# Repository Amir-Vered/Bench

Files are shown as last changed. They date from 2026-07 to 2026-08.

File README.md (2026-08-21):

# Bench

<p align="center">
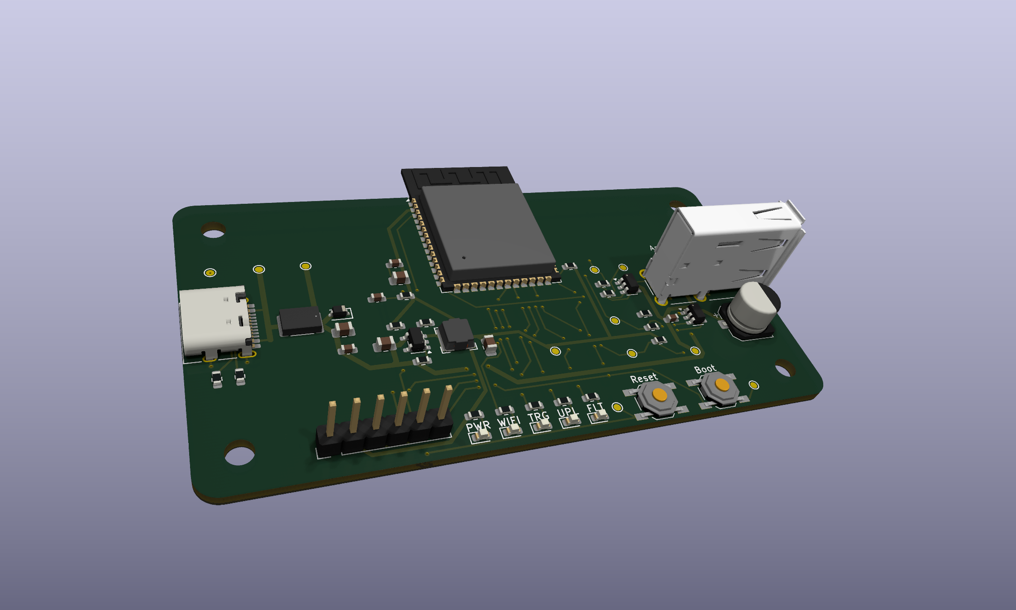
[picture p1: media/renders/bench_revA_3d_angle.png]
Bench Rev A render
  
</p>

<p align="center">
  
  
  
  
</p>

<p align="center">
  🎥 <a href="https://youtu.be/uZiKh8IRC8s">Video</a> &nbsp;•&nbsp; 🌐 <a href="https://amirvered.com/project/bench">Writeup</a>
</p>

<p align="center">
  <a href="#project-goals">Project Goals</a> •
  <a href="#system-overview">System Overview</a> •
  <a href="#diagrams">Diagrams</a> •
  <a href="#hardware">Hardware</a> •
  <a href="#software">Software</a> •
  <a href="#license">License</a>
</p>

---

*Bench... and it's not made out of wood?*

Here's the pitch:

TL;DR wires are annoying, let's put Bench in the middle of the Arduino workflow.

I love Arduino, it's perfect for prototyping your projects before making your PCBs. 
But, idk about you, the most annoying thing to me is the fact that the board is tied to my laptop.
And it's not a graceful connection, no, these wires are some of the most stale twisted things you've ever used, especially the uni lab ones.
This gets even worse when you're using a desktop computer.
But what if we put a device in the middle?

Enter: Bench.

Bench is a wifi upload dock for Arduino (built primarily for the Uno R3 because it's the one I use most).
Compile your sketch, run a command, and boom, it uploads to your device somewhere else.
No more wire, Arduino dev becomes a little less life-draining.

This is a simple little project, but it's open source, and I hope you find some use out of it.
Feel free to leave issues, fork, or really do whatever you want with it.

## Project Goals

My goals for this project were to:
- Improve the Arduino dev experience
- Develop my hardware, firmware, and software design skills
- Document a project from beginning to end

## System Overview

Let's get into the details.

At a high level:

1. The laptop compiles an Arduino sketch into a `.hex` file.
2. The CLI sends the `.hex` file to Bench over Wi-Fi.
3. The ESP32-S3 on Bench receives the upload request.
4. Bench opens a USB host serial connection to the Arduino Uno R3.
5. Bench triggers the Uno bootloader window.
6. Bench uploads the program to the ATmega328P flash memory.

Bench does not compile Arduino code on-board; compilation happens on the laptop.

## Diagrams

### Labeled Board

<p align="center">
  Bench Rev A labeled board
</p>

### System Block Diagram

<p align="center">
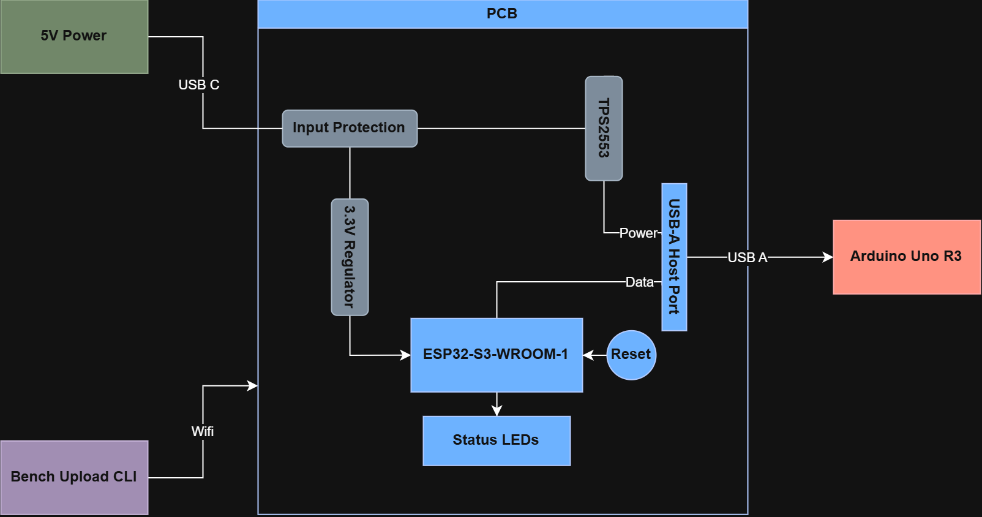
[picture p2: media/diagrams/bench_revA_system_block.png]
Bench Rev A system block diagram
  
</p>

### Power Path

<p align="center">
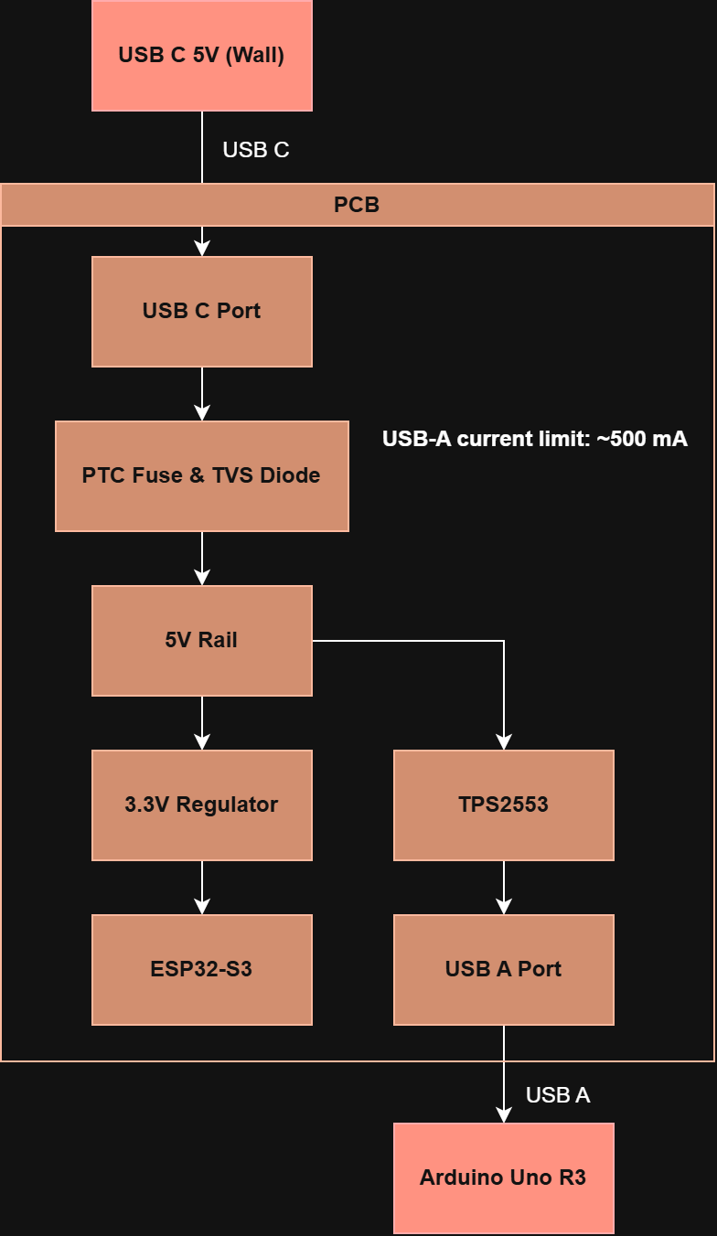
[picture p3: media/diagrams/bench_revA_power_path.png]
Bench Rev A power path
  
</p>

### Upload/Data Flow

<p align="center">
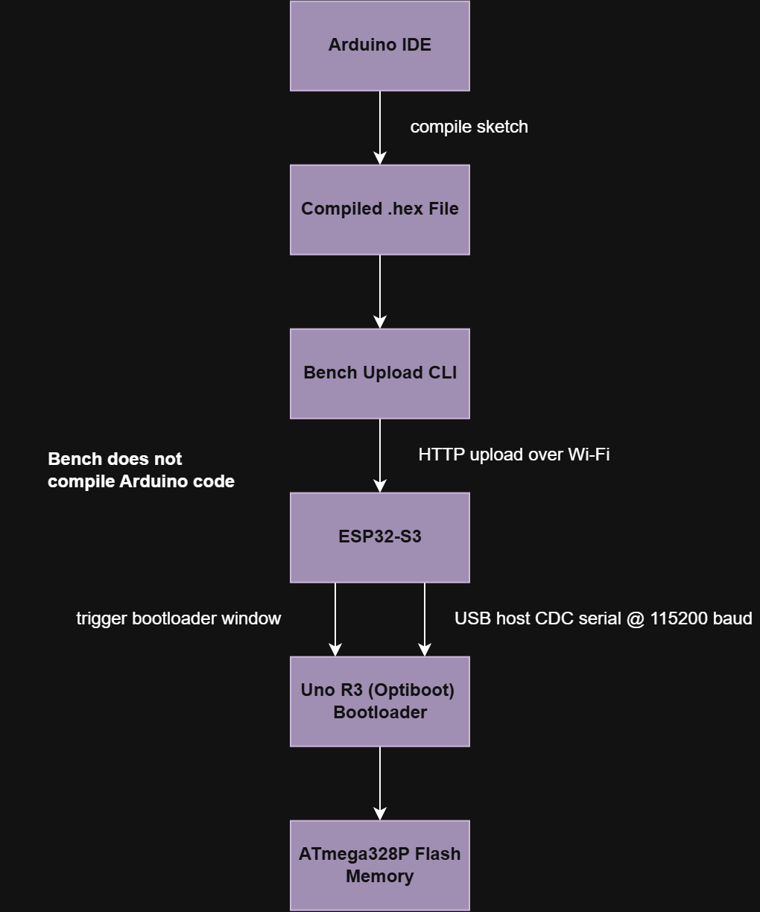
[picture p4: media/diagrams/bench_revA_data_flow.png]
Bench Rev A data flow
  
</p>

## Repository Structure

```text
bench/
├── hardware/
│   ├── kicad/
│   └── exports/
├── software/
│   ├── mock/
│   │   └── bench-mock-server/
│   ├── cli/
│   │   └── bench-upload/
│   └── firmware/
│       └── bench-fw/
├── media/
│   ├── diagrams/
│   ├── renders/
│   └── screenshots/
├── LICENSE-SOFTWARE
├── LICENSE-HARDWARE
└── README.md
```

## Hardware

Bench is built around the ESP32-S3-WROOM-1.

Major hardware blocks include:

- USB-C 5V input
- Input protection using a PTC fuse and TVS diode
- 3.3V buck regulator for the ESP32-S3
- ESP32-S3-WROOM-1 Wi-Fi microcontroller
- USB-A host output for the Arduino Uno R3
- TPS2553 current-limited USB power switch
- USB data ESD protection
- Status LEDs for power, Wi-Fi, target, upload, and fault states
- Reset and boot/config buttons

## Software

Bench includes three software components:

```text
software/
├── mock/
│   └── bench-mock-server/
├── cli/
│   └── bench-upload/
└── firmware/
    └── bench-fw/
```

### Mock Server

The mock server simulates a Bench device on a local computer. It is used to test the CLI without Bench hardware.

```powershell
cd software\mock\bench-mock-server
python -m venv .venv
.venv\Scripts\Activate.ps1
python -m pip install --upgrade pip
python -m pip install -e .
bench-mock --port 8080
```

Test the mock server:

```text
http://127.0.0.1:8080/api/v1/status
```

### CLI

The Bench Upload CLI runs on the laptop, and can communicate with the firmware or mock server.

```powershell
cd software\cli\bench-upload
python -m venv .venv
.venv\Scripts\Activate.ps1
python -m pip install --upgrade pip
python -m pip install -e .
```

#### *Here's how to use the commands, demoed on the mock server...*

Check Bench status:

```powershell
bench status --device http://localhost:8080
```

Upload a precompiled Intel HEX file:

```powershell
bench upload --hex path\to\sketch.ino.hex --device http://localhost:8080
```

Upload without target reset:

```powershell
bench upload --hex path\to\sketch.ino.hex --no-reset --device http://localhost:8080
```

Upload without verify:

```powershell
bench upload --hex path\to\sketch.ino.hex --no-verify --device http://localhost:8080
```

Compile an Arduino sketch with Arduino CLI, then upload:

```powershell
bench upload path\to\Blink --fqbn arduino:avr:uno --device http://localhost:8080
```

### Firmware

The firmware is an ESP-IDF project for the ESP32-S3.

```powershell
cd software\firmware\bench-fw
idf.py set-target esp32s3
idf.py build
```

Wi-Fi settings are configured locally with:

```powershell
idf.py menuconfig
```

Then open:

```text
Bench Configuration
```

and set:

```text
Wi-Fi SSID
Wi-Fi password
```

## Firmware Features

Current firmware includes:

- Wi-Fi station startup
- HTTP API server
    - `GET /api/v1/status`
    - `POST /api/v1/target/power`
    - `POST /api/v1/target/reset`
    - `GET /api/v1/logs`
    - `POST /api/v1/upload`
    - `GET /api/v1/upload/{job_id}`
- ESP32-S3 USB host CDC
- Arduino Uno R3 Optiboot/STK500 upload path (🤞😩)
- GPIO control for TPS2553 target power
- GPIO control for status LEDs

The firmware builds successfully for ESP32-S3, but I haven't had the chance to test it on hardware, so be careful.

## API Overview

Bench firmware and the mock server expose the same main HTTP API shape.

```text
GET  /api/v1/status
POST /api/v1/upload
GET  /api/v1/upload/{job_id}
POST /api/v1/target/power
POST /api/v1/target/reset
GET  /api/v1/logs
```

Primary upload states:

```text
idle
receiving
opening_target
bootloader_sync
uploading
verifying
success
failed
fault
```

Primary error codes:

```text
INVALID_HEX
NO_TARGET
POWER_FAULT
USB_OPEN_FAILED
BOOTLOADER_TIMEOUT
UPLOAD_FAILED
VERIFY_FAILED
POWER_DISABLED
```

## Current Status

Bench Rev A is a complete prototype, but I haven't had the chance to fabricate it yet.

I'm confident in my hardware and software design, but the firmware, well, let's just say it was my first time programming an ESP32-S3... 😅

Something else pretty cool about this project is the documentation. I've created a video, a post on my website, this repo, and so much more, with full diagrams and explanations.
It's been part of my goal to build more in public, and this is one of the projects I'm most proud of so far. 
My chess board (ICB, 1/26-6/26) was awesome, but its docs were scattered. 
Bench is hopefully the start of a more cohesive online doc cycle, stay tuned for more.

In terms of future Bench additions, if there is a Rev B, expect:
- more in-depth CLI
- hardware redesign, maybe
- 3D printable exterior / mounts
- and more

## License

* **Software:** Licensed under the **[MIT License](LICENSE-SOFTWARE)**.
* **Hardware:** Schematics and PCB layouts are licensed under the **[CERN-OHL-P-2.0](LICENSE-HARDWARE)** (CERN Open Hardware Licence Version 2 - Permissive).
* **Media & Documentation:** Renders, diagrams, and written assets are **© 2026 Amir Vered** unless otherwise stated. All rights reserved.

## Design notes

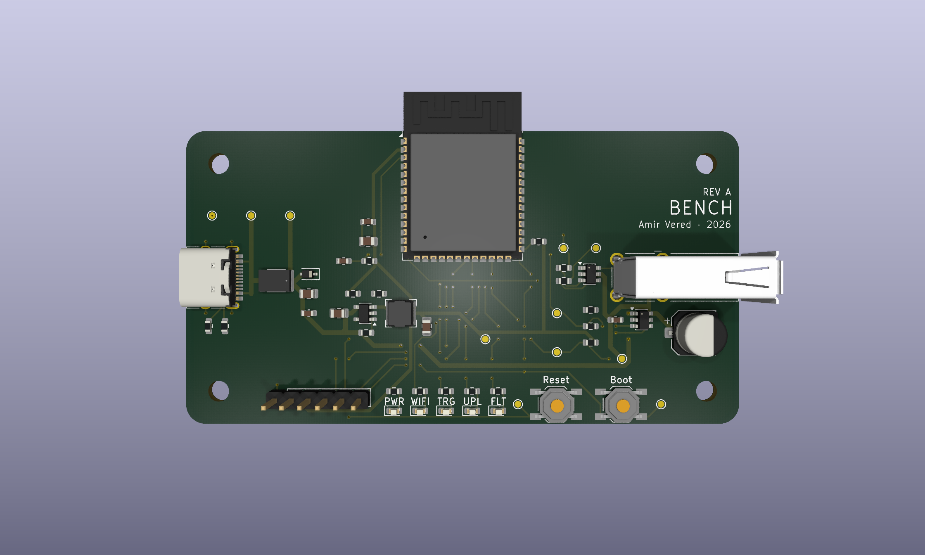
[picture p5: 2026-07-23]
media/renders/bench_revA_3d_top.png

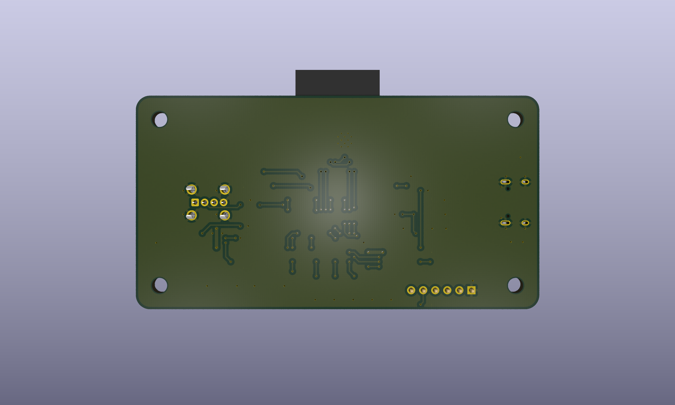
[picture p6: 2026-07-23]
media/renders/bench_revA_3d_bottom.png

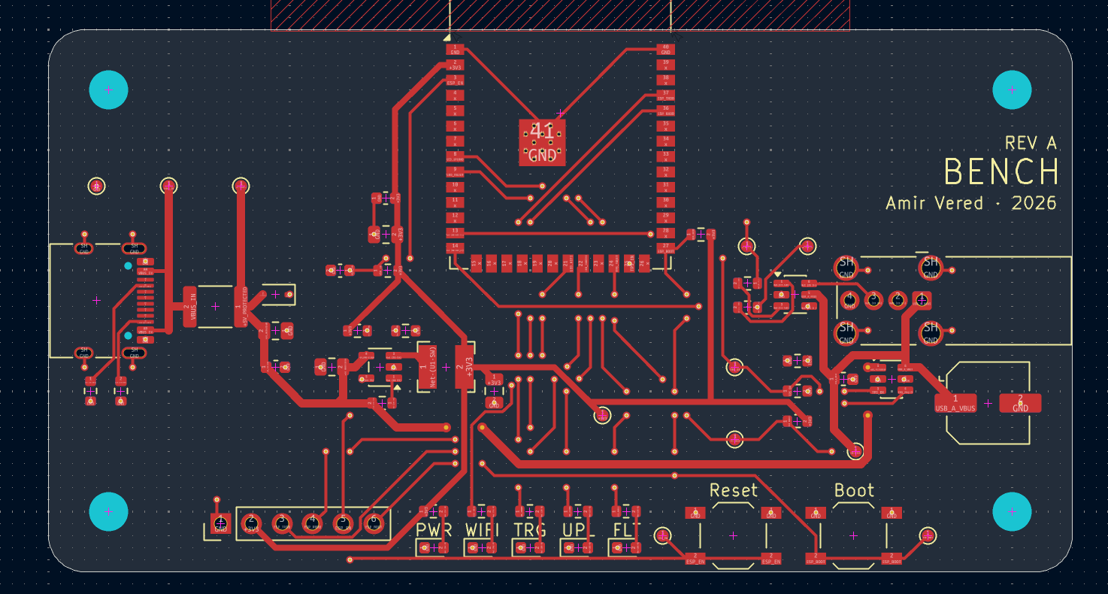
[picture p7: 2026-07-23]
media/screenshots/bench_revA_pcb_top_routing.png

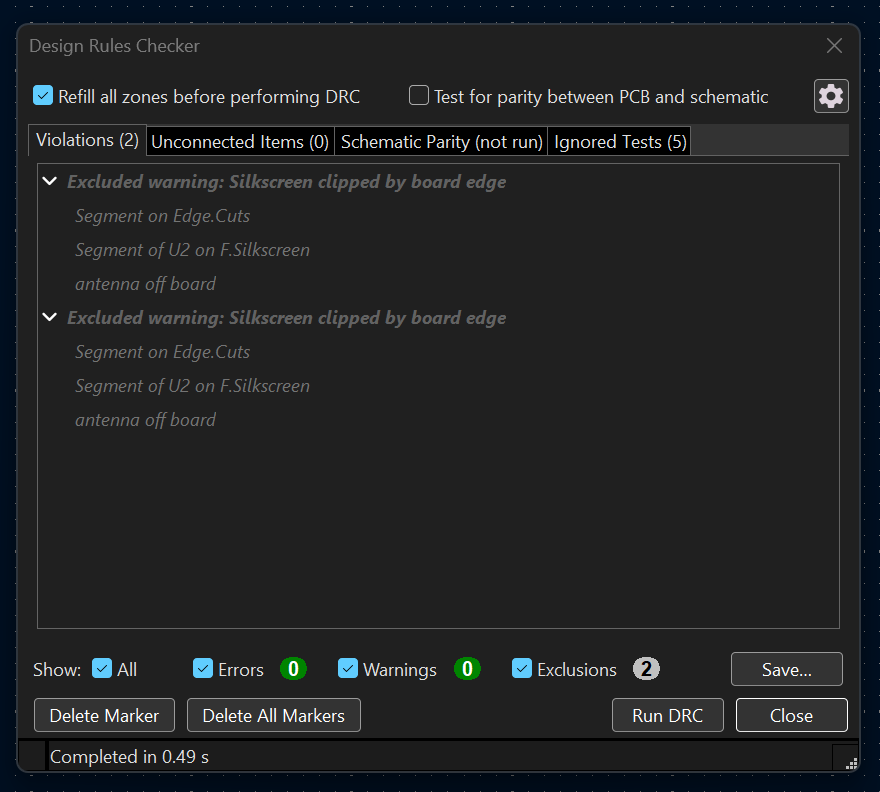
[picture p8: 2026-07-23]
media/screenshots/bench_revA_drc_clean.png

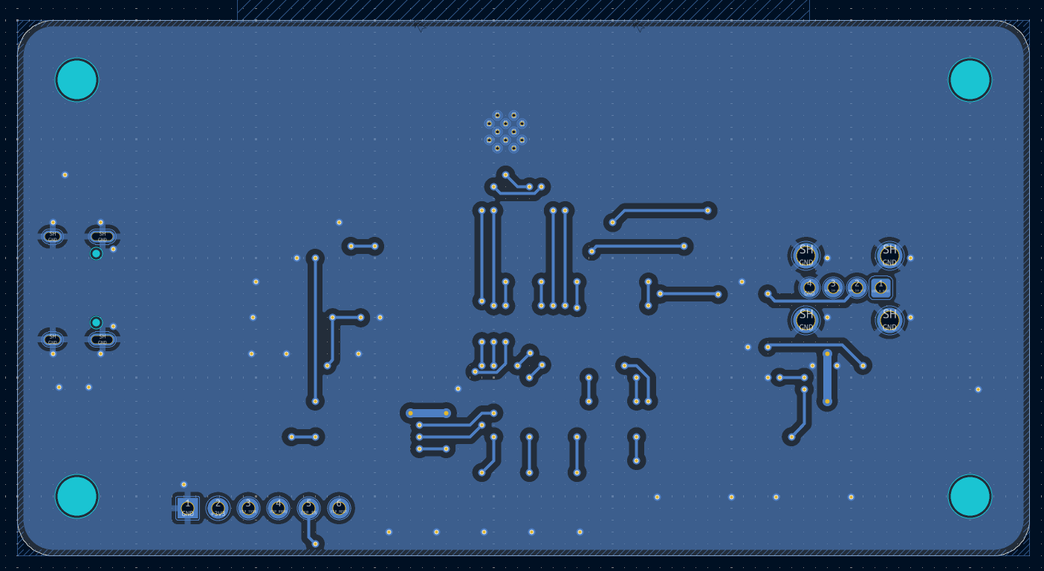
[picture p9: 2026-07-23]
media/screenshots/bench_revA_pcb_bottom_routing.png

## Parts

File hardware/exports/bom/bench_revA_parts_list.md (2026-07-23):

# Bench Rev A Parts List

Bench is a Wi-Fi USB-host upload dock for Arduino Uno R3 projects.

## Major Components

| Function | Part | Notes |
|---|---|---|
| Main controller | ESP32-S3-WROOM-1-N8R8 | Wi-Fi + USB host-capable module |
| USB power switch | TPS2553DBV | Current-limited USB-A VBUS switch |
| 3.3V buck regulator | TLV62569DBVR | 5V to 3.3V regulator |
| USB ESD protection | USBLC6-2SC6 | Protects USB-A D+/D− |
| Input TVS diode | TSD05 | Protects 5V input rail |
| USB-C input | USB-C receptacle | Power-only 5V input |
| USB-A output | USB-A receptacle | Target Arduino Uno R3 connection |

## Important Passive Values

| Reference | Value | Purpose |
|---|---:|---|
| R1, R2 | 5.1k | USB-C CC pulldowns |
| R3 | 453k | Buck feedback top resistor |
| R5 | 100k | Buck feedback bottom resistor |
| R8 | 59k | TPS2553 current-limit resistor for ~500mA target |
| R16, R17 | 22R | USB D+/D− series resistors |
| C8 | 120uF | USB-A VBUS bulk capacitance |

## Notes

- USB-C is power-only.
- USB-A acts as the host output port for Arduino Uno R3.
- R_ILIM = 59k for an approximate 500mA USB-A current-limit target.

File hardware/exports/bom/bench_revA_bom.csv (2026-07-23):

Reference | Qty | Value | DNP | Exclude from BOM | Exclude from Board | Footprint | Datasheet
C1,C3,C4,C6 | 4 | 10uF |  |  |  | Capacitor_SMD:C_0805_2012Metric
C2,C5,C7,C9 | 4 | 0.1uF |  |  |  | Capacitor_SMD:C_0603_1608Metric
C8 | 1 | 120uF |  |  |  | Capacitor_SMD:CP_Elec_6.3x5.8
D1 | 1 | TSD05 |  |  |  | Diode_SMD:D_SOD-323
D2 | 1 | LED_PWR |  |  |  | LED_SMD:LED_0603_1608Metric
D3 | 1 | LED_WIFI |  |  |  | LED_SMD:LED_0603_1608Metric
D4 | 1 | LED_TARGET |  |  |  | LED_SMD:LED_0603_1608Metric
D5 | 1 | LED_UPLOAD |  |  |  | LED_SMD:LED_0603_1608Metric
D6 | 1 | LED_FAULT |  |  |  | LED_SMD:LED_0603_1608Metric
F1 | 1 | 1A hold |  |  |  | Fuse:Fuse_1812_4532Metric
J1 | 1 | USB_C_Receptacle_USB2.0_16P |  |  |  | Connector_USB:USB_C_Receptacle_HRO_TYPE-C-31-M-12 | https://www.usb.org/sites/default/files/documents/usb_type-c.zip
J2 | 1 | J_ESP_PROG |  |  |  | Connector_PinHeader_2.54mm:PinHeader_1x06_P2.54mm_Vertical
J3 | 1 | USB_A |  |  |  | Connector_USB:USB_A_Wuerth_614004134726_Horizontal
L1 | 1 | 2.2uH |  |  |  | Inductor_SMD:L_Bourns-SRN4018
R1,R2 | 2 | 5.1k |  |  |  | Resistor_SMD:R_0603_1608Metric
R3 | 1 | 453k |  |  |  | Resistor_SMD:R_0603_1608Metric
R4,R5,R9 | 3 | 100k |  |  |  | Resistor_SMD:R_0603_1608Metric
R6,R7,R10 | 3 | 10k |  |  |  | Resistor_SMD:R_0603_1608Metric
R8 | 1 | 59k |  |  |  | Resistor_SMD:R_0603_1608Metric
R11,R12,R13,R14,R15 | 5 | 1k |  |  |  | Resistor_SMD:R_0603_1608Metric
R16,R17 | 2 | 22R |  |  |  | Resistor_SMD:R_0603_1608Metric
SW1 | 1 | Reset |  |  |  | Button_Switch_SMD:SW_SPST_TL3342
SW2 | 1 | Boot |  |  |  | Button_Switch_SMD:SW_SPST_TL3342
TP1 | 1 | TP_5V_PROTECTED |  |  |  | TestPoint:TestPoint_Pad_D1.0mm
TP2 | 1 | TP_3V3 |  |  |  | TestPoint:TestPoint_Pad_D1.0mm
TP3 | 1 | TP_VBUS_IN |  |  |  | TestPoint:TestPoint_Pad_D1.0mm
TP4 | 1 | TP_USB_A_VBUS |  |  |  | TestPoint:TestPoint_Pad_D1.0mm
TP5 | 1 | TP_GND |  |  |  | TestPoint:TestPoint_Pad_D1.0mm
TP6 | 1 | TP_USB_D- |  |  |  | TestPoint:TestPoint_Pad_D1.0mm
TP7 | 1 | TP_USB_D+ |  |  |  | TestPoint:TestPoint_Pad_D1.0mm
TP8 | 1 | TP_TPS_FAULT |  |  |  | TestPoint:TestPoint_Pad_D1.0mm
TP9 | 1 | TP_TPS_EN |  |  |  | TestPoint:TestPoint_Pad_D1.0mm
TP10 | 1 | TP_ESP_BOOT |  |  |  | TestPoint:TestPoint_Pad_D1.0mm
TP11 | 1 | TP_ESP_EN |  |  |  | TestPoint:TestPoint_Pad_D1.0mm
U1 | 1 | TLV62569DBVR |  |  |  | Package_TO_SOT_SMD:SOT-23-5 | http://www.ti.com/lit/ds/symlink/tlv62569.pdf
U2 | 1 | ESP32-S3-WROOM-1-N8R8 |  |  |  | RF_Module:ESP32-S3-WROOM-1 | https://www.espressif.com/sites/default/files/documentation/esp32-s3-wroom-1_wroom-1u_datasheet_en.pdf
U3 | 1 | USBLC6-2SC6 |  |  |  | Package_TO_SOT_SMD:SOT-23-6 | https://www.st.com/resource/en/datasheet/usblc6-2.pdf
U4 | 1 | TPS2553DBV |  |  |  | Package_TO_SOT_SMD:SOT-23-6

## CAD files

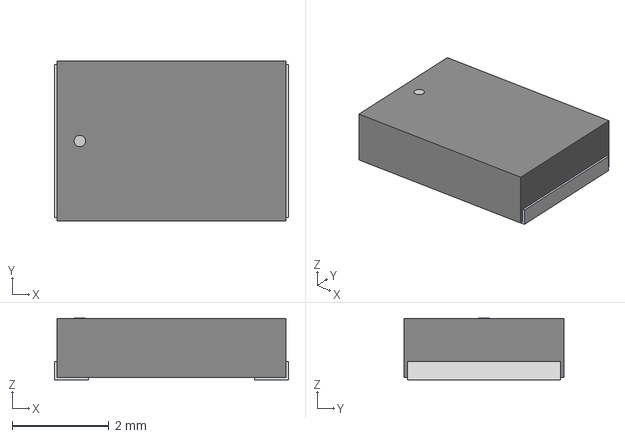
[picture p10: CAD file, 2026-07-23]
hardware/kicad/3dmodels/FUSE_1812L_LTF.step
4.83 x 3.30 x 1.27 mm

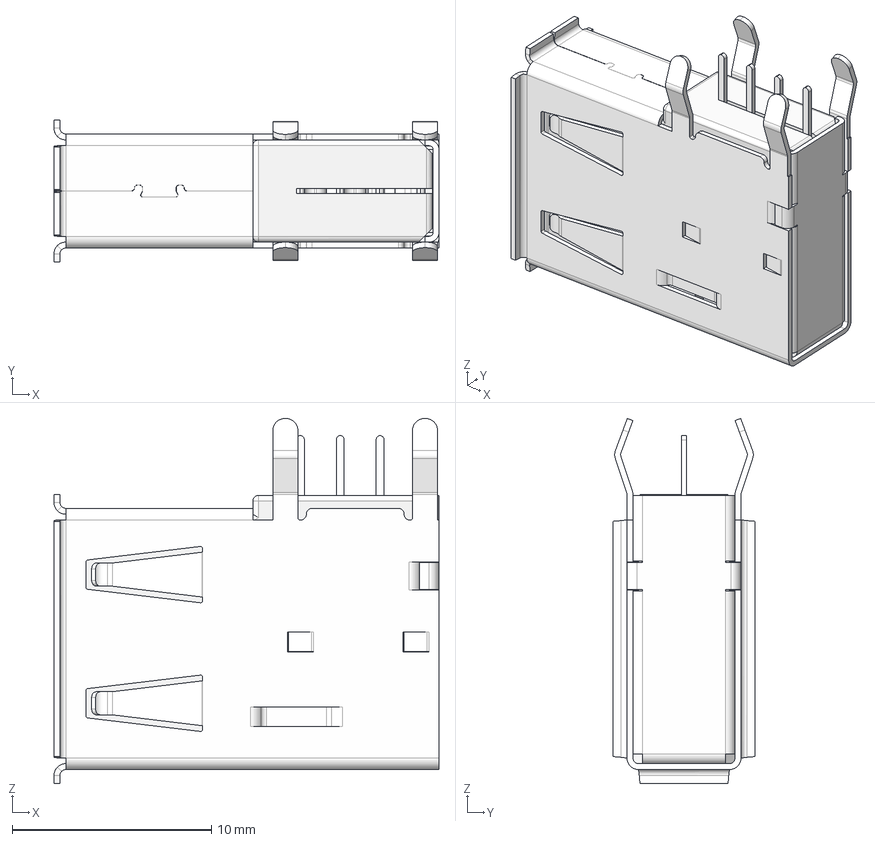
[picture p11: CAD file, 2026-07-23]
hardware/kicad/3dmodels/Download_STP_614004134726_rev1.stp
19.3 x 7.10 x 18.3 mm
Blech
Blech_Deckel
Pin_4
Gehäuse_Pin
Pin_3
Pin_2
Pin_1

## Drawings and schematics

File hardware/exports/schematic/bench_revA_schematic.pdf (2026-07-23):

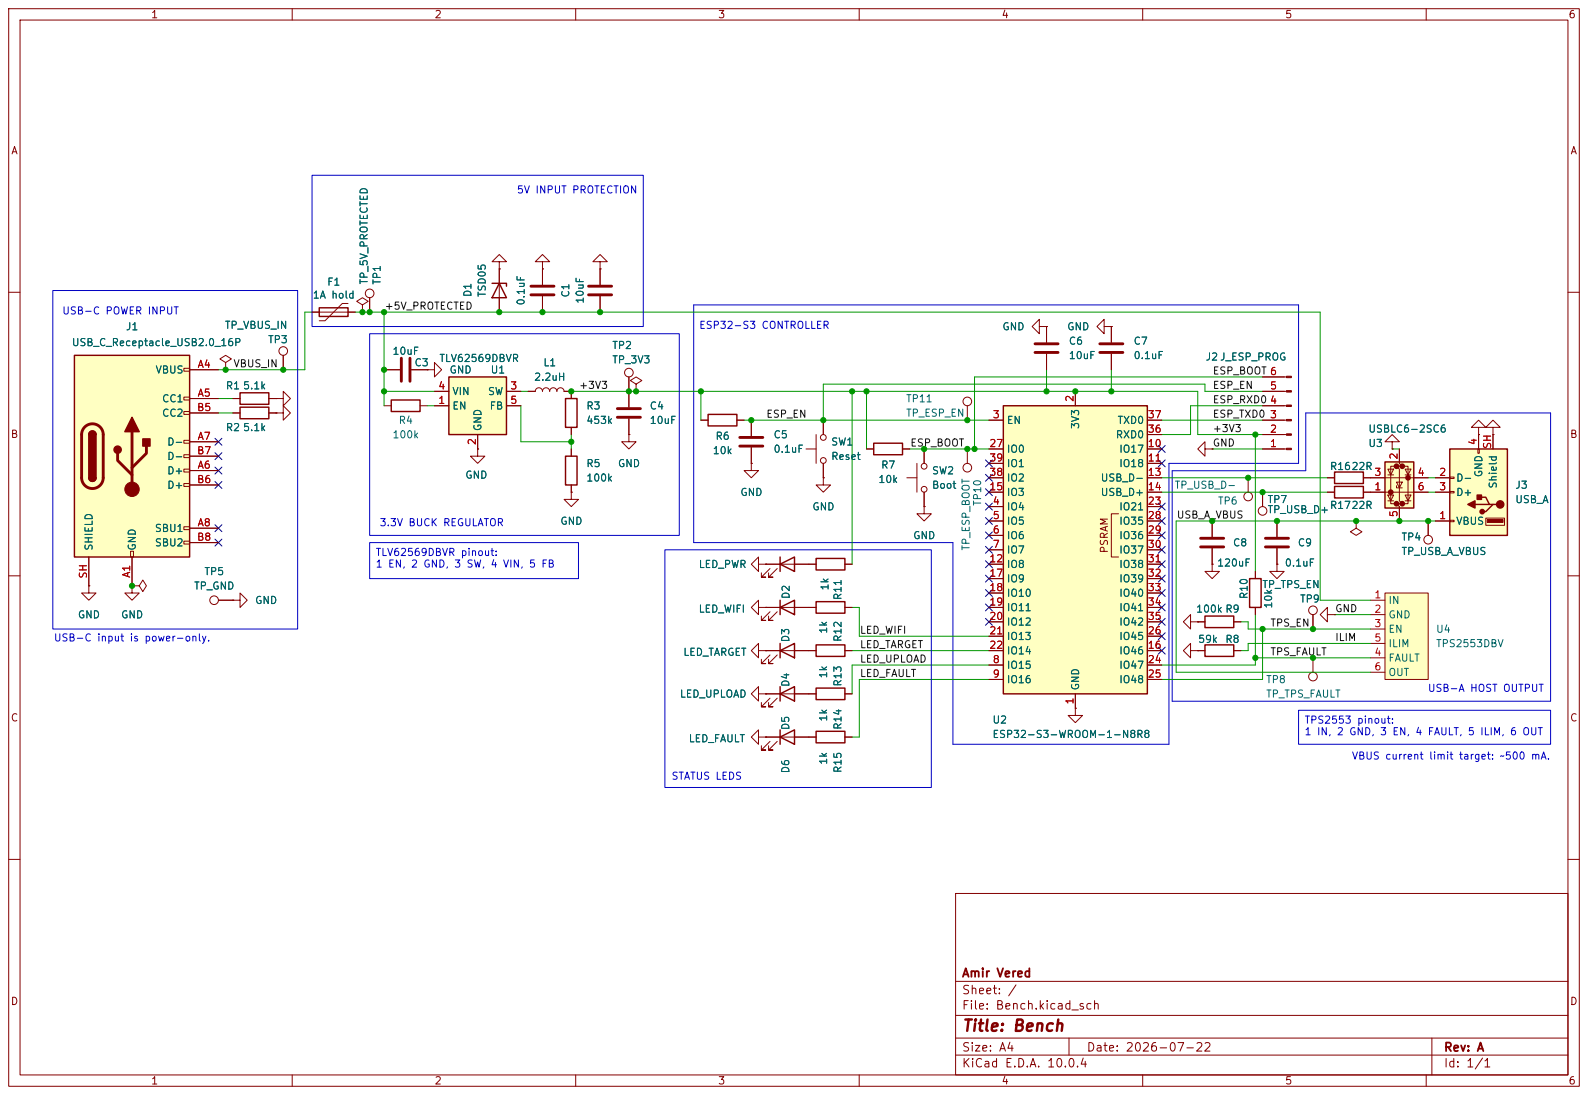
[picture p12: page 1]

IO14 22
IO15 8
IO16 9

FAULT 4

TPS2553 pinout: 1 IN, 2 GND, 3 EN, 4 FAULT, 5 ILIM, 6 OUT

Size: A4 | Rev: A
KiCad E.D.A. 10.0.4 | Id: 1/1

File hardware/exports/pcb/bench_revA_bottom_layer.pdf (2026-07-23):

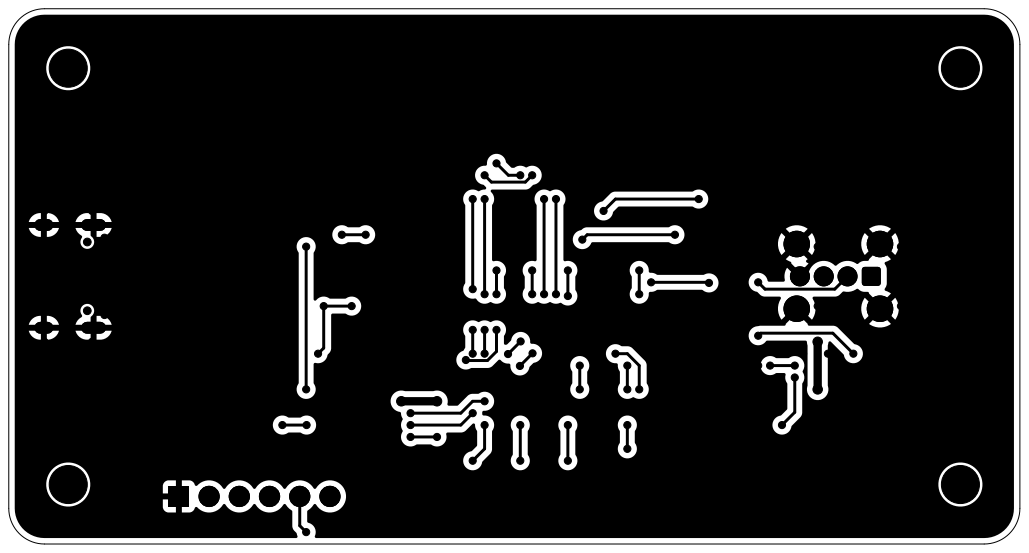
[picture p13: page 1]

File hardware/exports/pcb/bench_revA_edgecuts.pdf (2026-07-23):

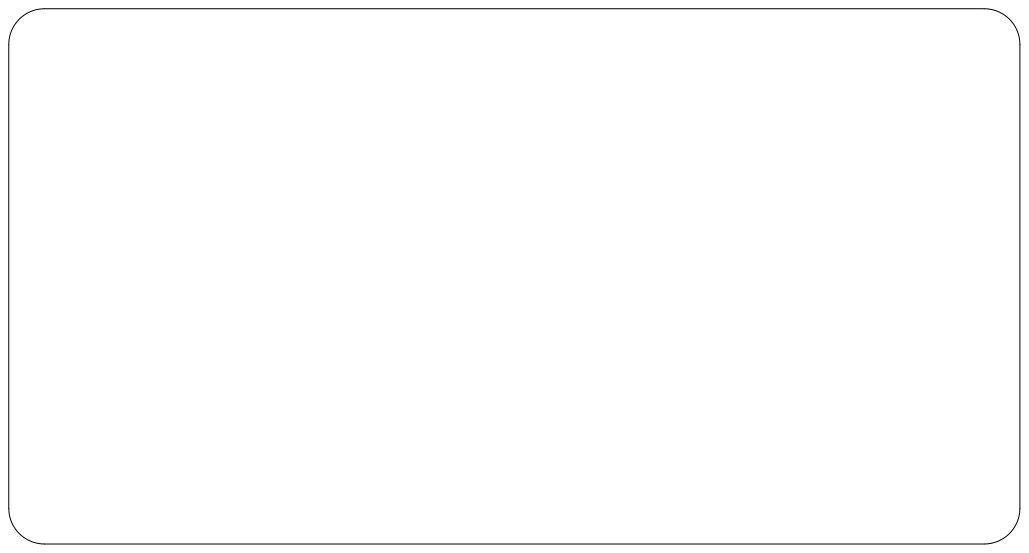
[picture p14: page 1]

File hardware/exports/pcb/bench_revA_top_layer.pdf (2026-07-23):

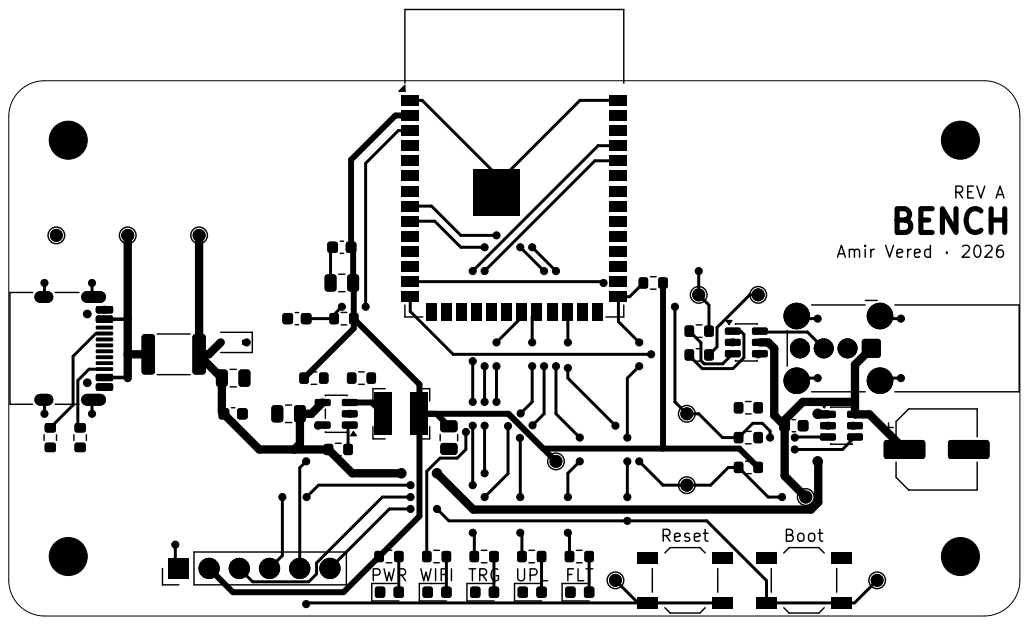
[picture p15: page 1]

Amir Vered · 2026 REV A BENCH

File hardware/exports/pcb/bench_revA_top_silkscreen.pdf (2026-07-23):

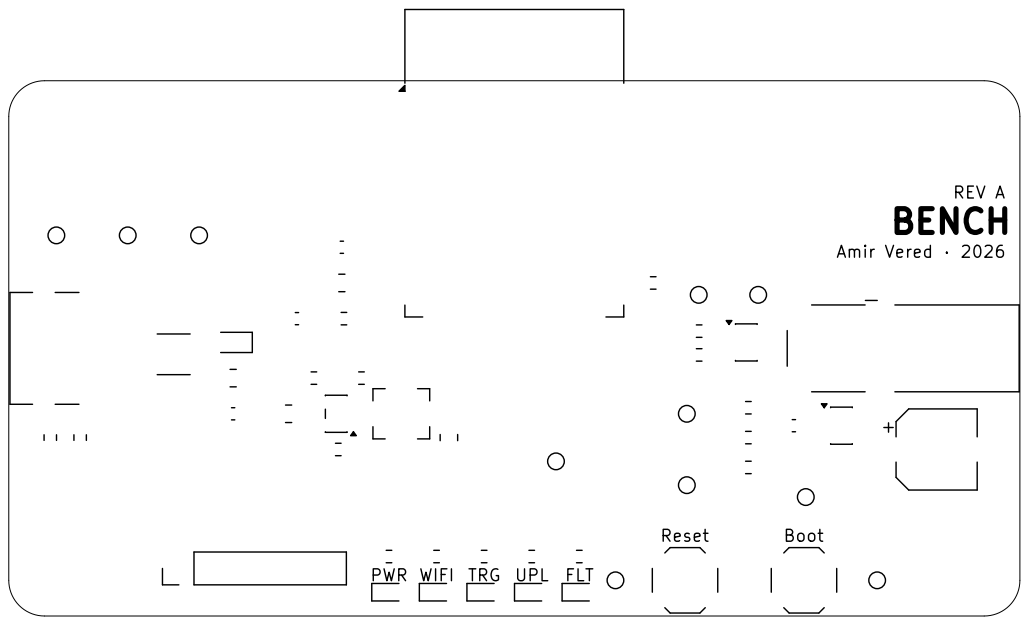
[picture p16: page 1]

Amir Vered · 2026 REV A BENCH

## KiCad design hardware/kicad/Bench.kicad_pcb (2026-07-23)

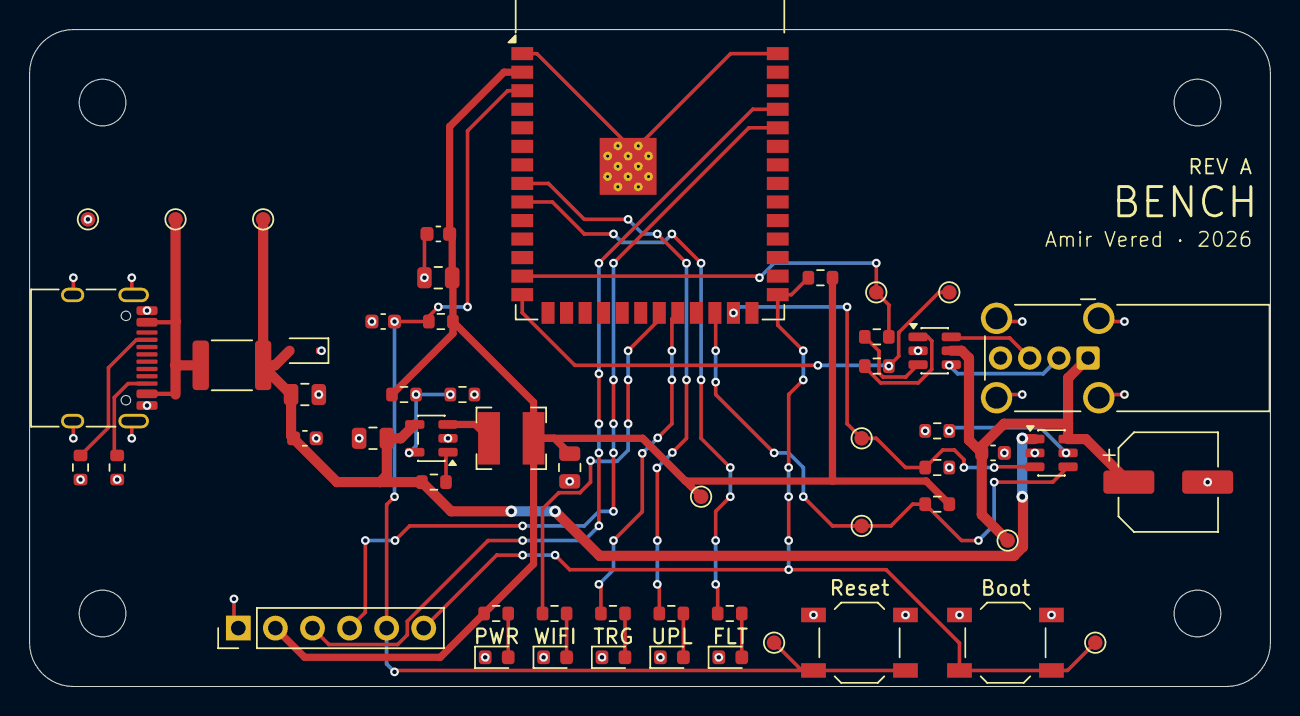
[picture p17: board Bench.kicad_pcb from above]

Board: 2 copper layers, 85.0 x 45.0 mm, 54 parts (0 on the bottom side), 32 nets.

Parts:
Boot: Boot; SW_SPST_TL3342
C1, C3, C4, C6: 10uF; C_0805_2012Metric
C2, C5, C7, C9: 0.1uF; C_0603_1608Metric
C8: 120uF; CP_Elec_6.3x5.8
D1: TSD05; D_SOD-323
F1: 1A hold; Fuse_1812_4532Metric
FLT: LED_FAULT; LED_0603_1608Metric
J1: USB_C; USB_C_Receptacle_HRO_TYPE-C-31-M-12
J2: J_ESP_PROG; PinHeader_1x06_P2.54mm_Vertical
J3: USB_A; USB_A_Wuerth_614004134726_Horizontal
L1: 2.2uH; L_Bourns-SRN4018
PWR: LED_PWR; LED_0603_1608Metric
R1, R2: 5.1k; R_0603_1608Metric
R3: 453k; R_0603_1608Metric
R4, R5, R9: 100k; R_0603_1608Metric
R6, R7, R10: 10k; R_0603_1608Metric
R8: 59k; R_0603_1608Metric
R11, R12, R13, R14, R15: 1k; R_0603_1608Metric
R16, R17: 22R; R_0603_1608Metric
Reset: Reset; SW_SPST_TL3342
TP1: TP_5V_PROTECTED; TestPoint_Pad_D1.0mm
TP2: TP_3V3; TestPoint_Pad_D1.0mm
TP3: TP_VBUS_IN; TestPoint_Pad_D1.0mm
TP4: TP_USB_A_VBUS; TestPoint_Pad_D1.0mm
TP5: TP_GND; TestPoint_Pad_D1.0mm
TP6: TP_USB_D-; TestPoint_Pad_D1.0mm
TP7: TP_USB_D+; TestPoint_Pad_D1.0mm
TP8: TP_TPS_FAULT; TestPoint_Pad_D1.0mm
TP9: TP_TPS_EN; TestPoint_Pad_D1.0mm
TP10: TP_ESP_BOOT; TestPoint_Pad_D1.0mm
TP11: TP_ESP_EN; TestPoint_Pad_D1.0mm
TRG: LED_TARGET; LED_0603_1608Metric
U1: TLV62569DBVR; SOT-23-5
U2: ESP32-S3-WROOM-1-N8R8; ESP32-S3-WROOM-1
U3: USBLC6-2SC6; SOT-23-6
U4: TPS2553DBV; SOT-23-6
UPL: LED_UPLOAD; LED_0603_1608Metric
WIFI: LED_WIFI; LED_0603_1608Metric

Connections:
/+3V3: C4.1, C6.2, C7.2, J2.2, L1.2, R3.1, R6.2, R7.2, R10.2, R11.1, TP2.1 (1_1), U2.2 (3V3)
/+5V_PROTECTED: C1.2, C2.1, C3.2, D1.2 (A), F1.1, R4.2, TP1.1 (1_1), U1.4 (VIN), U4.1 (IN)
/ESP_BOOT: Boot.2, J2.6, R7.1, TP10.1 (1_1), U2.27 (IO0)
/ESP_EN: C5.1, J2.5, R6.1, Reset.2, TP11.1 (1_1), U2.3 (EN)
/ESP_RXD0: J2.4, U2.36 (RXD0)
/ESP_TXD0: J2.3, U2.37 (TXD0)
/ILIM: R8.2, U4.5 (ILIM)
/LED_FAULT: R15.1, U2.9 (IO16)
/LED_TARGET: R13.1, U2.22 (IO14)
/LED_UPLOAD: R14.1, U2.8 (IO15)
/LED_WIFI: R12.1, U2.21 (IO13)
/TPS_EN: R9.1, TP9.1 (1_1), U2.25 (IO48), U4.3 (EN)
/TPS_FAULT: R10.1, TP8.1 (1_1), U2.24 (IO47), U4.4 (FAULT)
/USB_A_VBUS: C8.1, C9.1, J3.1 (VBUS), TP4.1 (1_1), U3.5 (VBUS), U4.6 (OUT)
/VBUS_IN: F1.2, J1.A4 (VBUS), J1.A9 (VBUS), J1.B4 (VBUS), J1.B9 (VBUS), TP3.1 (1_1)
GND: Boot.1, C1.1, C2.2, C3.1, C4.2, C5.2, C6.1, C7.1, C8.2, C9.2, D1.1 (K), FLT.1 (K), J1.A1 (GND), J1.A12 (GND), J1.B1 (GND), J1.B12 (GND), J1.SH (SHIELD), J2.1, J3.4 (GND), J3.SH (Shield), PWR.1 (K), R1.2, R2.1, R5.2, R8.1, R9.2, Reset.1, TP5.1 (1_1), TRG.1 (K), U1.2 (GND), U2.1 (GND), U2.40 (GND), U2.41 (GND), U3.2 (GND), U4.2 (GND), UPL.1 (K), WIFI.1 (K)
unnamed: PWR.2 (A), R11.2
unnamed: R12.2, WIFI.2 (A)
unnamed: R13.2, TRG.2 (A)
unnamed: R14.2, UPL.2 (A)
unnamed: FLT.2 (A), R15.2
unnamed: J1.A5 (CC1), R1.1
unnamed: J1.B5 (CC2), R2.2
unnamed: J3.3 (D+), U3.6 (I/O1)
unnamed: J3.2 (D-), U3.4 (I/O2)
unnamed: R16.2, U3.3 (I/O2)
unnamed: R17.2, U3.1 (I/O1)
unnamed: R4.1, U1.1 (EN)
unnamed: R3.2, R5.1, U1.5 (FB)
unnamed: L1.1, U1.3 (SW)
unnamed: R17.1, TP7.1 (1_1), U2.14 (USB_D+)
unnamed: R16.1, TP6.1 (1_1), U2.13 (USB_D-)

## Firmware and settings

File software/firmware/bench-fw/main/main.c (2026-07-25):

#include <stdio.h>
#include <string.h>
#include <stdbool.h>
#include <stdarg.h>
#include <stdlib.h>
#include <stdint.h>

#include "freertos/FreeRTOS.h"
#include "freertos/event_groups.h"
#include "freertos/semphr.h"
#include "freertos/task.h"

#include "esp_event.h"
#include "esp_http_server.h"
#include "esp_log.h"
#include "esp_netif.h"
#include "esp_wifi.h"
#include "nvs_flash.h"
#include "sdkconfig.h"

#include "usb/usb_host.h"
#include "usb/cdc_acm_host.h"

#include "driver/gpio.h"

#define WIFI_SSID CONFIG_BENCH_WIFI_SSID
#define WIFI_PASS CONFIG_BENCH_WIFI_PASSWORD

#define WIFI_CONNECTED_BIT BIT0
#define WIFI_FAIL_BIT      BIT1

#define LOG_LINE_COUNT 16
#define LOG_LINE_LEN   128

#define CDC_RX_BUF_SIZE 1024

#define UPLOAD_BODY_MAX_BYTES 160000
#define UNO_FLASH_SIZE        32768
#define UNO_PAGE_SIZE         128

#define STK_OK        0x10
#define STK_INSYNC    0x14
#define CRC_EOP       0x20
#define STK_GET_SYNC  0x30
#define STK_LOAD_ADDR 0x55
#define STK_PROG_PAGE 0x64
#define STK_READ_PAGE 0x74
#define STK_LEAVE     0x51

#define GPIO_LED_WIFI     GPIO_NUM_13
#define GPIO_LED_TARGET   GPIO_NUM_14
#define GPIO_LED_UPLOAD   GPIO_NUM_15
#define GPIO_LED_FAULT    GPIO_NUM_16

#define GPIO_TPS_FAULT    GPIO_NUM_47
#define GPIO_TPS_EN       GPIO_NUM_48

#define LED_ON            1
#define LED_OFF           0

#define TPS_EN_ON         1
#define TPS_EN_OFF        0

#define TPS_FAULT_ACTIVE  0

static const char *TAG = "bench-fw";

static EventGroupHandle_t wifi_event_group;
static int wifi_retry_count = 0;
static const int WIFI_MAX_RETRIES = 5;

static bool target_present = false;
static bool target_power_enabled = true;
static bool target_power_fault = false;

static char log_lines[LOG_LINE_COUNT][LOG_LINE_LEN];
static int log_line_index = 0;

static TaskHandle_t usb_host_task_handle = NULL;
static bool usb_host_ready = false;

static SemaphoreHandle_t cdc_rx_mutex = NULL;
static SemaphoreHandle_t cdc_rx_sem = NULL;
static uint8_t cdc_rx_buf[CDC_RX_BUF_SIZE];
static size_t cdc_rx_head = 0;
static size_t cdc_rx_tail = 0;

static SemaphoreHandle_t upload_mutex = NULL;
static bool upload_running = false;
static int upload_job_counter = 0;
static int upload_progress = 0;
static char upload_job_id[32] = "";
static char upload_state[32] = "idle";
static char upload_message[96] = "idle";
static char upload_error[40] = "";

typedef struct {
    char *hex_text;
    size_t hex_len;
    bool reset;
    bool verify;
} upload_task_args_t;

typedef struct {
    uint8_t image[UNO_FLASH_SIZE];
    uint32_t highest_addr;
} flash_image_t;

static void bench_log(const char *fmt, ...);
static void bench_gpio_update_status_leds(void);

static void bench_log(const char *fmt, ...) {
    va_list args;
    va_start(args, fmt);

    vsnprintf(log_lines[log_line_index], LOG_LINE_LEN, fmt, args);

    va_end(args);

    ESP_LOGI(TAG, "%s", log_lines[log_line_index]);

    log_line_index = (log_line_index + 1) % LOG_LINE_COUNT;
}

static esp_err_t send_json(httpd_req_t *req, const char *json) {
    httpd_resp_set_type(req, "application/json");
    return httpd_resp_send(req, json, HTTPD_RESP_USE_STRLEN);
}

static esp_err_t send_json_status(httpd_req_t *req, const char *status, const char *json) {
    httpd_resp_set_status(req, status);
    return send_json(req, json);
}

static char *find_bytes(const char *haystack, size_t haystack_len, const char *needle, size_t needle_len) {
    if (needle_len == 0 || haystack_len < needle_len) {
        return NULL;
    }

    for (size_t i = 0; i <= haystack_len - needle_len; i++) {
        if (memcmp(haystack + i, needle, needle_len) == 0) {
            return (char *) haystack + i;
        }
    }

    return NULL;
}

static bool header_has_name(const char *headers, size_t headers_len, const char *name) {
    char pattern[64];

    snprintf(pattern, sizeof(pattern), "name=\"%s\"", name);

    return find_bytes(headers, headers_len, pattern, strlen(pattern)) != NULL;
}

static bool field_is_false(const char *data, size_t len) {
    while (len > 0 && (*data == ' ' || *data == '\r' || *data == '\n' || *data == '\t')) {
        data++;
        len--;
    }

    while (len > 0 &&
           (data[len - 1] == ' ' ||
            data[len - 1] == '\r' ||
            data[len - 1] == '\n' ||
            data[len - 1] == '\t')) {
        len--;
    }

    return len == 5 && memcmp(data, "false", 5) == 0;
}

static esp_err_t copy_part(char **out, size_t *out_len, const char *data, size_t len) {
    char *copy = malloc(len + 1);

    if (copy == NULL) {
        return ESP_ERR_NO_MEM;
    }

    memcpy(copy, data, len);
    copy[len] = '\0';

    *out = copy;
    *out_len = len;

    return ESP_OK;
}

static esp_err_t extract_upload_parts(
    char *body,
    size_t body_len,
    const char *content_type,
    upload_task_args_t *args
) {
    args->hex_text = NULL;
    args->hex_len = 0;
    args->reset = true;
    args->verify = true;

    if (content_type == NULL || strstr(content_type, "multipart/form-data") == NULL) {
        return copy_part(&args->hex_text, &args->hex_len, body, body_len);
    }

    const char *boundary_key = "boundary=";
    const char *boundary_start = strstr(content_type, boundary_key);

    if (boundary_start == NULL) {
        return ESP_ERR_INVALID_ARG;
    }

    boundary_start += strlen(boundary_key);

    char boundary[96] = {0};
    size_t boundary_len = 0;

    if (*boundary_start == '"') {
        boundary_start++;

        while (*boundary_start != '\0' &&
               *boundary_start != '"' &&
               boundary_len < sizeof(boundary) - 1) {
            boundary[boundary_len++] = *boundary_start++;
        }
    } else {
        while (*boundary_start != '\0' &&
               *boundary_start != ';' &&
               boundary_len < sizeof(boundary) - 1) {
            boundary[boundary_len++] = *boundary_start++;
        }
    }

    if (boundary_len == 0) {
        return ESP_ERR_INVALID_ARG;
    }

    char delimiter[128];

    snprintf(delimiter, sizeof(delimiter), "--%s", boundary);

    size_t delimiter_len = strlen(delimiter);
    char *cursor = body;
    char *body_end = body + body_len;

    while (cursor < body_end) {
        char *part = find_bytes(cursor, body_end - cursor, delimiter, delimiter_len);

        if (part == NULL) {
            break;
        }

        part += delimiter_len;

        if (part + 2 <= body_end && part[0] == '-' && part[1] == '-') {
            break;
        }

        if (part + 2 <= body_end && part[0] == '\r' && part[1] == '\n') {
            part += 2;
        }

        char *headers_end = find_bytes(part, body_end - part, "\r\n\r\n", 4);

        if (headers_end == NULL) {
            break;
        }

        char *content_start = headers_end + 4;
        char *next = find_bytes(content_start, body_end - content_start, delimiter, delimiter_len);

        if (next == NULL) {
            break;
        }

        char *content_end = next;

        if (content_end - content_start >= 2 &&
            content_end[-2] == '\r' &&
            content_end[-1] == '\n') {
            content_end -= 2;
        }

        size_t headers_len = headers_end - part;
        size_t content_len = content_end - content_start;

        if (header_has_name(part, headers_len, "file")) {
            esp_err_t result = copy_part(&args->hex_text, &args->hex_len, content_start, content_len);

            if (result != ESP_OK) {
                return result;
            }
        } else if (header_has_name(part, headers_len, "reset")) {
            if (field_is_false(content_start, content_len)) {
                args->reset = false;
            }
        } else if (header_has_name(part, headers_len, "verify")) {
            if (field_is_false(content_start, content_len)) {
                args->verify = false;
            }
        }

        cursor = next;
    }

    if (args->hex_text == NULL || args->hex_len == 0) {
        return ESP_ERR_NOT_FOUND;
    }

    return ESP_OK;
}

static void upload_set_state(const char *state, int progress, const char *message, const char *error) {
    if (upload_mutex != NULL) {
        xSemaphoreTake(upload_mutex, portMAX_DELAY);
    }

    strncpy(upload_state, state, sizeof(upload_state) - 1);
    upload_state[sizeof(upload_state) - 1] = '\0';

    upload_progress = progress;

    strncpy(upload_message, message, sizeof(upload_message) - 1);
    upload_message[sizeof(upload_message) - 1] = '\0';

    if (error != NULL) {
        strncpy(upload_error, error, sizeof(upload_error) - 1);
        upload_error[sizeof(upload_error) - 1] = '\0';
    } else {
        upload_error[0] = '\0';
    }

    if (upload_mutex != NULL) {
        xSemaphoreGive(upload_mutex);
    }

    bench_gpio_update_status_leds();
}

static void bench_gpio_set_leds(bool wifi, bool target, bool upload, bool fault) {
    gpio_set_level(GPIO_LED_WIFI, wifi ? LED_ON : LED_OFF);
    gpio_set_level(GPIO_LED_TARGET, target ? LED_ON : LED_OFF);
    gpio_set_level(GPIO_LED_UPLOAD, upload ? LED_ON : LED_OFF);
    gpio_set_level(GPIO_LED_FAULT, fault ? LED_ON : LED_OFF);
}

static void bench_gpio_set_target_power(bool enabled) {
    gpio_set_level(GPIO_TPS_EN, enabled ? TPS_EN_ON : TPS_EN_OFF);
    target_power_enabled = enabled;
}

static bool bench_gpio_read_power_fault(void) {
    target_power_fault = gpio_get_level(GPIO_TPS_FAULT) == TPS_FAULT_ACTIVE;
    return target_power_fault;
}

static void bench_gpio_update_status_leds(void) {
    bool upload_active = false;

    if (upload_mutex != NULL) {
        xSemaphoreTake(upload_mutex, portMAX_DELAY);
        upload_active = upload_running;
        xSemaphoreGive(upload_mutex);
    }

    bench_gpio_set_leds(
        true,
        target_present,
        upload_active,
        target_power_fault
    );
}

static esp_err_t bench_gpio_init(void) {
    gpio_config_t output_config = {
        .pin_bit_mask =
            (1ULL << GPIO_LED_WIFI) |
            (1ULL << GPIO_LED_TARGET) |
            (1ULL << GPIO_LED_UPLOAD) |
            (1ULL << GPIO_LED_FAULT) |
            (1ULL << GPIO_TPS_EN),
        .mode = GPIO_MODE_OUTPUT,
        .pull_up_en = GPIO_PULLUP_DISABLE,
        .pull_down_en = GPIO_PULLDOWN_DISABLE,
        .intr_type = GPIO_INTR_DISABLE,
    };

    ESP_ERROR_CHECK(gpio_config(&output_config));

    gpio_config_t input_config = {
        .pin_bit_mask = (1ULL << GPIO_TPS_FAULT),
        .mode = GPIO_MODE_INPUT,
        .pull_up_en = GPIO_PULLUP_ENABLE,
        .pull_down_en = GPIO_PULLDOWN_DISABLE,
        .intr_type = GPIO_INTR_DISABLE,
    };

    ESP_ERROR_CHECK(gpio_config(&input_config));

    bench_gpio_set_target_power(true);
    bench_gpio_read_power_fault();
    bench_gpio_update_status_leds();

    bench_log("GPIO initialized");

    return ESP_OK;
}

static int hex_nibble(char c) {
    if (c >= '0' && c <= '9') {
        return c - '0';
    }

    if (c >= 'a' && c <= 'f') {
        return c - 'a' + 10;
    }

    if (c >= 'A' && c <= 'F') {
        return c - 'A' + 10;
    }

    return -1;
}

static esp_err_t parse_hex_byte(const char *text, uint8_t *value) {
    int high = hex_nibble(text[0]);
    int low = hex_nibble(text[1]);

    if (high < 0 || low < 0) {
        return ESP_ERR_INVALID_ARG;
    }

    *value = (uint8_t) ((high << 4) | low);

    return ESP_OK;
}

static esp_err_t parse_intel_hex(const char *text, size_t len, flash_image_t *flash) {
    memset(flash->image, 0xFF, sizeof(flash->image));
    flash->highest_addr = 0;

    uint32_t base_addr = 0;
    bool saw_eof = false;

    const char *cursor = text;
    const char *end = text + len;

    while (cursor < end) {
        while (cursor < end && (*cursor == '\r' || *cursor == '\n' || *cursor == ' ' || *cursor == '\t')) {
            cursor++;
        }

        if (cursor >= end) {
            break;
        }

        const char *line_start = cursor;

        while (cursor < end && *cursor != '\r' && *cursor != '\n') {
            cursor++;
        }

        size_t line_len = cursor - line_start;

        if (line_len == 0) {
            continue;
        }

        if (line_start[0] != ':') {
            return ESP_ERR_INVALID_ARG;
        }

        if (((line_len - 1) % 2) != 0 || line_len < 11) {
            return ESP_ERR_INVALID_SIZE;
        }

        size_t record_len = (line_len - 1) / 2;
        uint8_t record[280];

        if (record_len > sizeof(record)) {
            return ESP_ERR_INVALID_SIZE;
        }

        for (size_t i = 0; i < record_len; i++) {
            esp_err_t result = parse_hex_byte(line_start + 1 + (i * 2), &record[i]);

            if (result != ESP_OK) {
                return result;
            }
        }

        uint8_t checksum = 0;

        for (size_t i = 0; i < record_len; i++) {
            checksum = (uint8_t) (checksum + record[i]);
        }

        if (checksum != 0) {
            return ESP_ERR_INVALID_CRC;
        }

        uint8_t byte_count = record[0];
        uint16_t offset = ((uint16_t) record[1] << 8) | record[2];
        uint8_t record_type = record[3];

        if (record_len != (size_t) byte_count + 5) {
            return ESP_ERR_INVALID_SIZE;
        }

        if (record_type == 0x00) {
            uint32_t absolute_addr = base_addr + offset;

            if (absolute_addr + byte_count > UNO_FLASH_SIZE) {
                return ESP_ERR_INVALID_SIZE;
            }

            memcpy(&flash->image[absolute_addr], &record[4], byte_count);

            if (absolute_addr + byte_count > flash->highest_addr) {
                flash->highest_addr = absolute_addr + byte_count;
            }
        } else if (record_type == 0x01) {
            saw_eof = true;
            break;
        } else if (record_type == 0x02) {
            if (byte_count != 2) {
                return ESP_ERR_INVALID_SIZE;
            }

            base_addr = (((uint32_t) record[4] << 8) | record[5]) << 4;
        } else if (record_type == 0x04) {
            if (byte_count != 2) {
                return ESP_ERR_INVALID_SIZE;
            }

            base_addr = (((uint32_t) record[4] << 8) | record[5]) << 16;
        }
    }

    if (!saw_eof) {
        return ESP_ERR_INVALID_ARG;
    }

    return ESP_OK;
}

static void cdc_rx_clear(void) {
    if (cdc_rx_mutex != NULL) {
        xSemaphoreTake(cdc_rx_mutex, portMAX_DELAY);
    }

    cdc_rx_head = 0;
    cdc_rx_tail = 0;

    if (cdc_rx_mutex != NULL) {
        xSemaphoreGive(cdc_rx_mutex);
    }

    while (cdc_rx_sem != NULL && xSemaphoreTake(cdc_rx_sem, 0) == pdTRUE) {
    }
}

static bool cdc_rx_push(const uint8_t *data, size_t len) {
    if (cdc_rx_mutex == NULL || cdc_rx_sem == NULL) {
        return false;
    }

    xSemaphoreTake(cdc_rx_mutex, portMAX_DELAY);

    for (size_t i = 0; i < len; i++) {
        size_t next_head = (cdc_rx_head + 1) % CDC_RX_BUF_SIZE;

        if (next_head == cdc_rx_tail) {
            cdc_rx_tail = (cdc_rx_tail + 1) % CDC_RX_BUF_SIZE;
        }

        cdc_rx_buf[cdc_rx_head] = data[i];
        cdc_rx_head = next_head;
        xSemaphoreGive(cdc_rx_sem);
    }

    xSemaphoreGive(cdc_rx_mutex);

    return true;
}

static bool cdc_rx_pop(uint8_t *value) {
    bool has_data = false;

    xSemaphoreTake(cdc_rx_mutex, portMAX_DELAY);

    if (cdc_rx_tail != cdc_rx_head) {
        *value = cdc_rx_buf[cdc_rx_tail];
        cdc_rx_tail = (cdc_rx_tail + 1) % CDC_RX_BUF_SIZE;
        has_data = true;
    }

    xSemaphoreGive(cdc_rx_mutex);

    return has_data;
}

static esp_err_t cdc_read_exact(uint8_t *data, size_t len, uint32_t timeout_ms) {
    TickType_t start = xTaskGetTickCount();
    TickType_t timeout_ticks = pdMS_TO_TICKS(timeout_ms);

    for (size_t i = 0; i < len; i++) {
        while (!cdc_rx_pop(&data[i])) {
            TickType_t now = xTaskGetTickCount();

            if ((now - start) >= timeout_ticks) {
                return ESP_ERR_TIMEOUT;
            }

            TickType_t remaining = timeout_ticks - (now - start);

            if (xSemaphoreTake(cdc_rx_sem, remaining) != pdTRUE) {
                return ESP_ERR_TIMEOUT;
            }
        }
    }

    return ESP_OK;
}

static esp_err_t stk_expect_ok(uint32_t timeout_ms) {
    uint8_t response[2];

    esp_err_t result = cdc_read_exact(response, sizeof(response), timeout_ms);

    if (result != ESP_OK) {
        return result;
    }

    if (response[0] != STK_INSYNC || response[1] != STK_OK) {
        return ESP_FAIL;
    }

    return ESP_OK;
}

static esp_err_t stk_tx_expect_ok(cdc_acm_dev_hdl_t cdc_handle, const uint8_t *data, size_t len, uint32_t timeout_ms) {
    cdc_rx_clear();

    esp_err_t result = cdc_acm_host_data_tx_blocking(cdc_handle, data, len, timeout_ms);

    if (result != ESP_OK) {
        return result;
    }

    return stk_expect_ok(timeout_ms);
}

static esp_err_t stk_sync(cdc_acm_dev_hdl_t cdc_handle) {
    const uint8_t sync_cmd[] = {
        STK_GET_SYNC,
        CRC_EOP,
    };

    for (int attempt = 0; attempt < 25; attempt++) {
        esp_err_t result = stk_tx_expect_ok(cdc_handle, sync_cmd, sizeof(sync_cmd), 150);

        if (result == ESP_OK) {
            return ESP_OK;
        }

        vTaskDelay(pdMS_TO_TICKS(100));
    }

    return ESP_ERR_TIMEOUT;
}

static esp_err_t stk_load_address(cdc_acm_dev_hdl_t cdc_handle, uint32_t byte_addr) {
    uint16_t word_addr = (uint16_t) (byte_addr / 2);

    uint8_t cmd[] = {
        STK_LOAD_ADDR,
        (uint8_t) (word_addr & 0xFF),
        (uint8_t) ((word_addr >> 8) & 0xFF),
        CRC_EOP,
    };

    return stk_tx_expect_ok(cdc_handle, cmd, sizeof(cmd), 500);
}

static esp_err_t stk_program_page(cdc_acm_dev_hdl_t cdc_handle, const uint8_t *page, size_t page_len) {
    uint8_t cmd[UNO_PAGE_SIZE + 5];

    if (page_len > UNO_PAGE_SIZE) {
        return ESP_ERR_INVALID_SIZE;
    }

    cmd[0] = STK_PROG_PAGE;
    cmd[1] = (uint8_t) ((page_len >> 8) & 0xFF);
    cmd[2] = (uint8_t) (page_len & 0xFF);
    cmd[3] = 'F';

    memcpy(&cmd[4], page, page_len);

    cmd[4 + page_len] = CRC_EOP;

    return stk_tx_expect_ok(cdc_handle, cmd, page_len + 5, 1000);
}

static esp_err_t stk_read_page(cdc_acm_dev_hdl_t cdc_handle, uint8_t *page, size_t page_len) {
    uint8_t cmd[] = {
        STK_READ_PAGE,
        (uint8_t) ((page_len >> 8) & 0xFF),
        (uint8_t) (page_len & 0xFF),
        'F',
        CRC_EOP,
    };

    cdc_rx_clear();

    esp_err_t result = cdc_acm_host_data_tx_blocking(cdc_handle, cmd, sizeof(cmd), 500);

    if (result != ESP_OK) {
        return result;
    }

    uint8_t insync = 0;
    result = cdc_read_exact(&insync, 1, 1000);

    if (result != ESP_OK) {
        return result;
    }

    if (insync != STK_INSYNC) {
        return ESP_FAIL;
    }

    result = cdc_read_exact(page, page_len, 1000);

    if (result != ESP_OK) {
        return result;
    }

    uint8_t ok = 0;
    result = cdc_read_exact(&ok, 1, 1000);

    if (result != ESP_OK) {
        return result;
    }

    if (ok != STK_OK) {
        return ESP_FAIL;
    }

    return ESP_OK;
}

static void stk_leave_programming(cdc_acm_dev_hdl_t cdc_handle) {
    const uint8_t leave_cmd[] = {
        STK_LEAVE,
        CRC_EOP,
    };

    (void) stk_tx_expect_ok(cdc_handle, leave_cmd, sizeof(leave_cmd), 500);
}
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
void app_main(void) {
    ESP_LOGI(TAG, "Bench firmware booting");
    ESP_LOGI(TAG, "Target MCU: ESP32-S3");

    upload_mutex = xSemaphoreCreateMutex();
    cdc_rx_mutex = xSemaphoreCreateMutex();
    cdc_rx_sem = xSemaphoreCreateCounting(CDC_RX_BUF_SIZE, 0);

    if (upload_mutex == NULL || cdc_rx_mutex == NULL || cdc_rx_sem == NULL) {
        ESP_LOGE(TAG, "Failed to create synchronization primitives");
        abort();
    }

    esp_err_t nvs_result = nvs_flash_init();

    if (nvs_result == ESP_ERR_NVS_NO_FREE_PAGES ||
        nvs_result == ESP_ERR_NVS_NEW_VERSION_FOUND) {
        ESP_ERROR_CHECK(nvs_flash_erase());
        nvs_result = nvs_flash_init();
    }

    ESP_ERROR_CHECK(nvs_result);

    bench_log("Bench firmware booted");

    ESP_ERROR_CHECK(bench_gpio_init());
    ESP_ERROR_CHECK(bench_usb_init());

    wifi_init_sta();

    start_http_server();

    while (1) {
        bench_log(
            "alive: target_present=%d power_enabled=%d power_fault=%d upload_running=%d",
            target_present,
            target_power_enabled,
            target_power_fault,
            upload_running
        );

        vTaskDelay(pdMS_TO_TICKS(5000));
    }
}
